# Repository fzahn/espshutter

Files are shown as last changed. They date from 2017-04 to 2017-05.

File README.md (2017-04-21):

#ESP Irrigation Interface

This code is used to control 8 solenoid valves via ESP8266.
The solenoids of the valves are connected via ULN2803 darlington array to the GPIOs of the ESP8266

The watering system has one main valve, which is connected to  valve1. This valve always has to be opened, when another valve is opened

They are attached as follows:

GPIO10 -> Valve 1 (main valve)
GPIO15  -> Valve 2
GPIO4  -> Valve 3
GPIO5  -> Valve 4
GPIO13 -> Valve 5
GPIO12 -> Valve 6
GPIO14 -> Valve 7
GPIO16 -> Valve 8

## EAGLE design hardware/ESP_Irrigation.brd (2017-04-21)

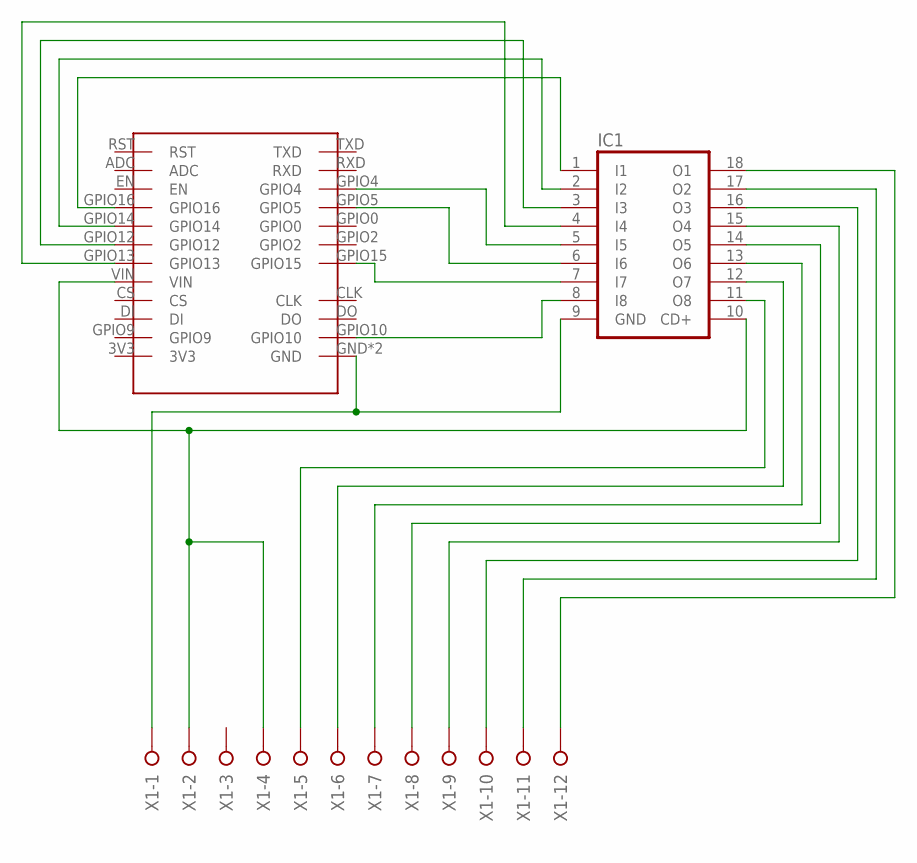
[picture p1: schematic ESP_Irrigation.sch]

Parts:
IC1: ULN2803A; DIL18
U$1: ESP12ADAPTERBOARD
X1: W237-12P

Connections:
unnamed: IC1.17 (O2), X1.11
unnamed: IC1.9 (GND), U$1.GND, U$1.GND1 (GND), X1.1
unnamed: IC1.11 (O8), X1.5
unnamed: IC1.8 (I8), U$1.GPIO10
unnamed: IC1.7 (I7), U$1.GPIO15
unnamed: IC1.5 (I5), U$1.GPIO4
unnamed: IC1.6 (I6), U$1.GPIO5
unnamed: IC1.4 (I4), U$1.GPIO13
unnamed: IC1.3 (I3), U$1.GPIO12
unnamed: IC1.12 (O7), X1.6
unnamed: IC1.13 (O6), X1.7
unnamed: IC1.14 (O5), X1.8
unnamed: IC1.15 (O4), X1.9
unnamed: IC1.16 (O3), X1.10
unnamed: IC1.10 (CD+), U$1.VIN, X1.2, X1.4
unnamed: IC1.18 (O1), X1.12
unnamed: IC1.1 (I1), U$1.GPIO16
unnamed: IC1.2 (I2), U$1.GPIO14

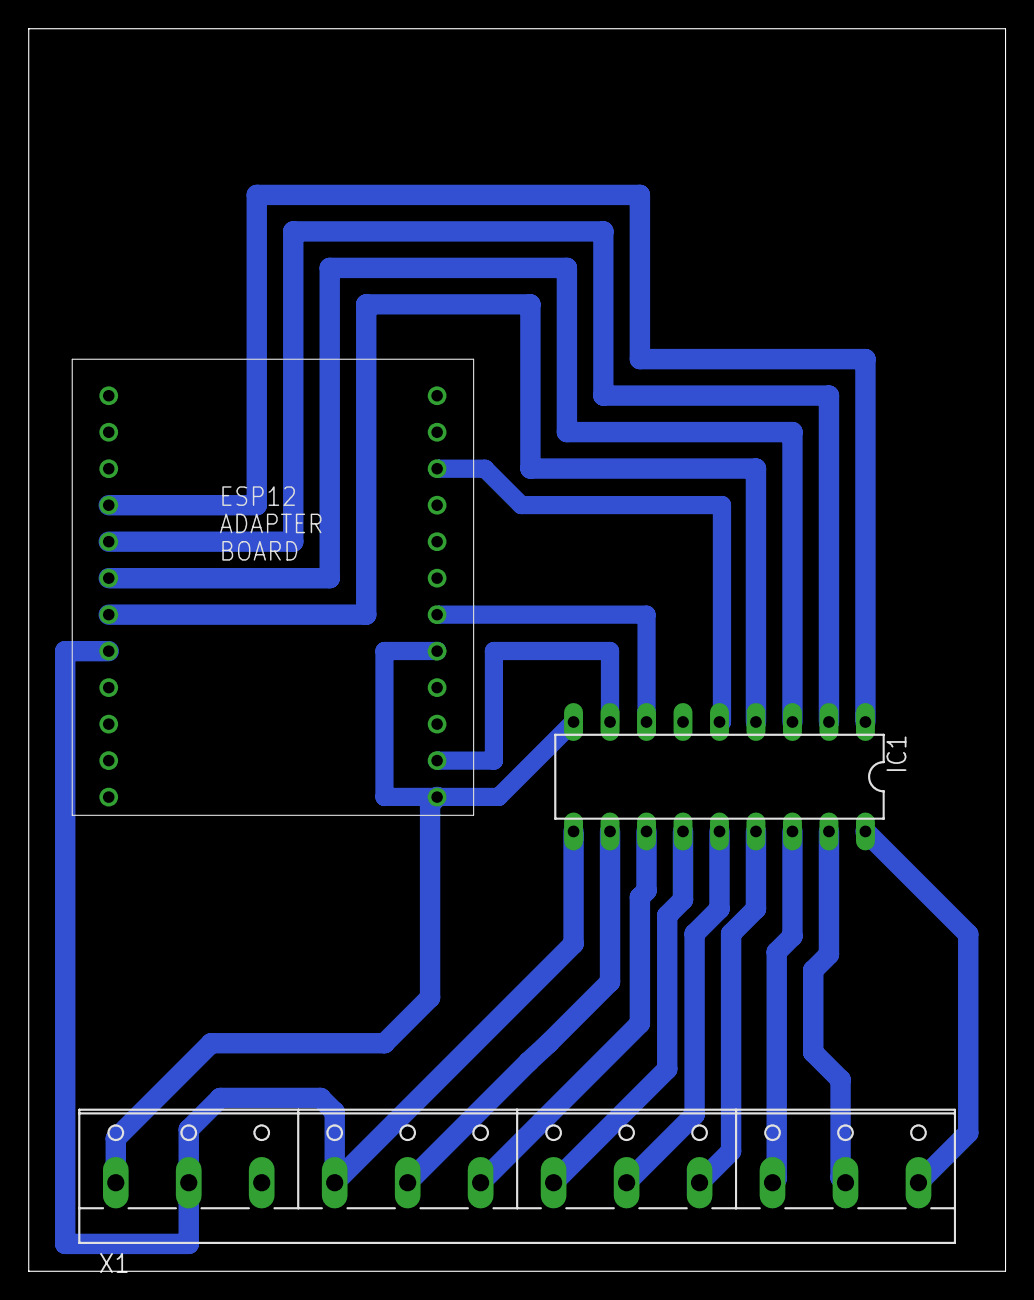
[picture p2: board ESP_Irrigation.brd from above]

Board: 2 copper layers, 68.0 x 86.5 mm, 3 parts (0 on the bottom side), 18 nets.

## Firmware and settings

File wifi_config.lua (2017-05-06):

--Function to save WiFi-parameters into file-system as wlancfg.lua
function save_wifi_param(ssid,password,mqttserver,mqttbasetopic)
 file.remove("wlancfg.lua");
 file.open("wlancfg.lua","w+");
 w = file.writeline('-- Tell the chip to connect to thi access point');
 w = file.writeline('wifi.setmode(wifi.STATION)');
 w = file.writeline('wifi.sta.config("' .. ssid .. '","' .. password .. '")');
 w = file.writeline('mqttserver="' .. mqttserver ..'"');
 w = file.writeline('mqttbasetopic="' .. mqttbasetopic ..'"'); 
 file.close();
 ssid,password,bssid_set,bssid=nil,nil,nil,nil
end

---push_button_Functions

solenoids = {}
solenoids[1]=12
solenoids[2]=8
solenoids[3]=2
solenoids[4]=1
solenoids[5]=7
solenoids[6]=6
solenoids[7]=5
solenoids[8]=0


function open_valve(solenoid)
	if (solenoid>1) then	
		gpio.write(solenoids[solenoid],gpio.HIGH)
		m:publish(mqttbasetopic .. solenoid .."/value", "open",0,0)
		print("Valve " .. solenoid .. " :opened\n")
	else
		gpio.write(solenoids[solenoid],gpio.HIGH)
		m:publish(mqttbasetopic .. solenoid .."/value", "open",0,0)
		print("Valve " .. solenoid .. " :opened and shutdown timer started\n")
		minuten=0
		tmr.alarm(1,60000,tmr.ALARM_AUTO,function()
			if (minuten<59) then
				minuten=minuten+1
				print("Valve 1 will be opened for the next " .. 60-minuten .. " minutes!\n")			
			else
				print("Valve 1 maximum runtime reached -> shutdown")
				close_valve(1)
				tmr.stop(1)
				tmr.unregister(1)
			end
		end
		)
	end
end


function close_valve(solenoid)
	gpio.write(solenoids[solenoid],gpio.LOW)
	m:publish(mqttbasetopic .. solenoid .."/value", "close",0,0)
	print("Valve " .. solenoid .. " :closed\n")
	if(solenoid==1) then
		tmr.stop(1)
		tmr.unregister(1)
	end
end




--MQTT Subsystem
function initmqtt()
	m = mqtt.Client("GARDENIRRIGATION", 120, "user", "pass")
	function mqttsubscribe()    
		m:subscribe(mqttbasetopic .. "1/command",0, function() print("subscribe success") end)
		m:subscribe(mqttbasetopic .. "2/command",0, function() print("subscribe success") end)
		m:subscribe(mqttbasetopic .. "3/command",0, function() print("subscribe success") end)
		m:subscribe(mqttbasetopic .. "4/command",0, function() print("subscribe success") end)
		m:subscribe(mqttbasetopic .. "5/command",0, function() print("subscribe success") end)
		m:subscribe(mqttbasetopic .. "6/command",0, function() print("subscribe success") end)
		m:subscribe(mqttbasetopic .. "7/command",0, function() print("subscribe success") end)
		m:subscribe(mqttbasetopic .. "8/command",0, function() print("subscribe success") end) 
	end
	m:on("connect", mqttsubscribe)
	
	m:on("message", function(client,topic,data)
		if (data=="open") then
			if topic==mqttbasetopic .. "1/command" then open_valve(1) end
			if topic==mqttbasetopic .. "2/command" then open_valve(2) end
			if topic==mqttbasetopic .. "3/command" then open_valve(3) end
			if topic==mqttbasetopic .. "4/command" then open_valve(4) end
			if topic==mqttbasetopic .. "5/command" then open_valve(5) end
			if topic==mqttbasetopic .. "6/command" then open_valve(6) end
			if topic==mqttbasetopic .. "7/command" then open_valve(7) end
			if topic==mqttbasetopic .. "8/command" then open_valve(8) end			
		elseif (data=="close") then
			if topic==mqttbasetopic .. "1/command" then close_valve(1) end
			if topic==mqttbasetopic .. "2/command" then close_valve(2) end
			if topic==mqttbasetopic .. "3/command" then close_valve(3) end
			if topic==mqttbasetopic .. "4/command" then close_valve(4) end
			if topic==mqttbasetopic .. "5/command" then close_valve(5) end
			if topic==mqttbasetopic .. "6/command" then close_valve(6) end
			if topic==mqttbasetopic .. "7/command" then close_valve(7) end
			if topic==mqttbasetopic .. "8/command" then close_valve(8) end		
		end		
	end
	)
	
	
	m:connect(mqttserver,1883,0)
	
end






--init_logic run once after successfully established network-connection 
function init_logic()


-- startServer
 dofile("webserver.lc")
 startWebServer()
 initmqtt()
 tmr.alarm(2, 1000, 0, function()
    m:publish(mqttbasetopic .. "1/command", "close",0,0)
    m:publish(mqttbasetopic .. "2/command", "close",0,0)
    m:publish(mqttbasetopic .. "3/command", "close",0,0)
    m:publish(mqttbasetopic .. "4/command", "close",0,0)
    m:publish(mqttbasetopic .. "5/command", "close",0,0)
    m:publish(mqttbasetopic .. "6/command", "close",0,0)
    m:publish(mqttbasetopic .. "7/command", "close",0,0)
    m:publish(mqttbasetopic .. "8/command", "close",0,0) 
	end
 )
--register MDNS
 mdns.register("gartenbewaesserung", { description="ESP Gartenbewaesserung", service="http", port="80" }) 
end


function init_gpio()
	gpio.mode(solenoids[1], gpio.OUTPUT)
	gpio.write(solenoids[1], gpio.LOW)
	gpio.mode(solenoids[2], gpio.OUTPUT)
	gpio.write(solenoids[2], gpio.LOW)
	gpio.mode(solenoids[3], gpio.OUTPUT)
	gpio.write(solenoids[3], gpio.LOW)
	gpio.mode(solenoids[4], gpio.OUTPUT)
	gpio.write(solenoids[4], gpio.LOW)
	gpio.mode(solenoids[5], gpio.OUTPUT)
	gpio.write(solenoids[5], gpio.LOW)
	gpio.mode(solenoids[6], gpio.OUTPUT)
	gpio.write(solenoids[6], gpio.LOW)
	gpio.mode(solenoids[7], gpio.OUTPUT)
	gpio.write(solenoids[7], gpio.LOW)
	gpio.mode(solenoids[8], gpio.OUTPUT)
	gpio.write(solenoids[8], gpio.LOW)
end


--MAIN PROGRAM ENTRY POINT, CALLED FROM init.lua

--if unable to connect for 30 seconds, start enduser_setup-routine
--load Wifi-configuration and try to connect

init_gpio()
dofile("wlancfg.lua")


connect_counter = 0
tmr.alarm(0, 100, 1, function()
 if wifi.sta.status() ~= 5 then
    connect_counter = connect_counter + 1
    print("Connecting to AP...")
    if(connect_counter == 300) then
      tmr.stop(0)
      print("Starting WiFi setup mode")
      enduser_setup.start(
       function()
        ssid,password,bssid_set,bssid=wifi.sta.getconfig()
        save_wifi_param(ssid,password,"192.168.0.1","/garten/irrigation/");
        print("Connected to wifi as:" .. wifi.sta.getip());
        print("Saved parameters in wlancfg.lua");
        init_logic();
       end,
       function(err, str)
        print("enduser_setup: Err #:" .. err .. ": " .. str);
       end
      )
    end
  else
   tmr.stop(0)
   tmr.unregister(0)
   print('IP: ',wifi.sta.getip())
   init_logic()
  end
 end
)
      
--at this point we should be ready to go....

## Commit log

2017-04-03 Function movemiddle to getthe shutter half down (double click on down-button)
2017-04-21 Modified version to control garden irrigation valves
2017-04-21 Fixed small errors, new Valve->GPIO table, added hardware
    [ESP_Irrigation.brd, ESP_Irrigation.sch]
2017-04-21 adapted to new hardware-layout (GPIO to Valve)
2017-05-06 Failsave mode added: Valve 1 will definitely shutdown after 60 minutes, because of reasons....
    [wifi_config.lua]
